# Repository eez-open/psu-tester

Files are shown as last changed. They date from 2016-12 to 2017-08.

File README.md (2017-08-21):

PCB tester for H24005 power supply's Power board r5B12 (or later) and AUX power module that can be used during PCBA and final quality assurance process. Require [Arduino Leonardo](https://www.arduino.cc/en/Main/ArduinoBoardLeonardo) board (attached on the opposite side of the PCB) and sketch with various test cases.

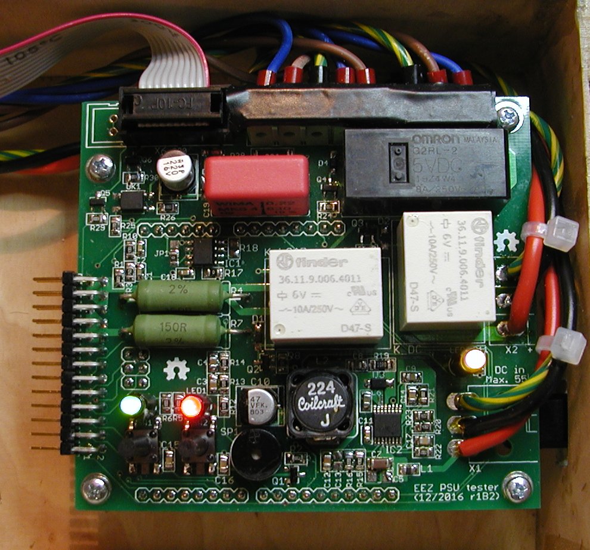
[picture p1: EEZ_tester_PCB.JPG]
EEZ tester


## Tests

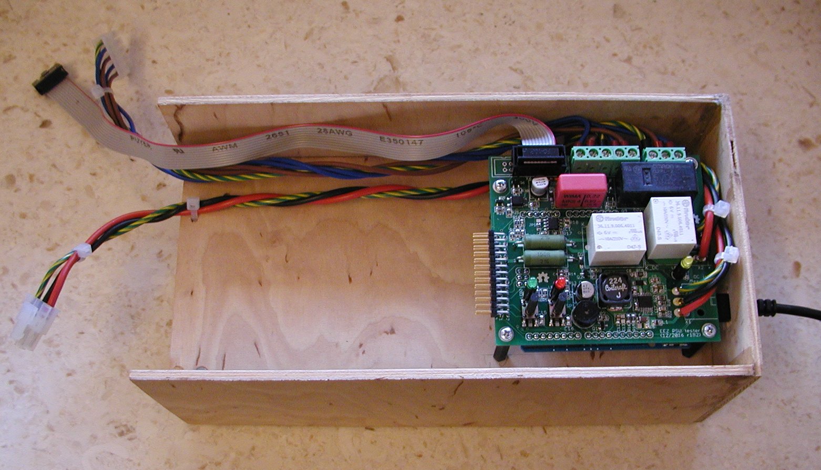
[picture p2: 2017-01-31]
EEZ tester (top view).JPG

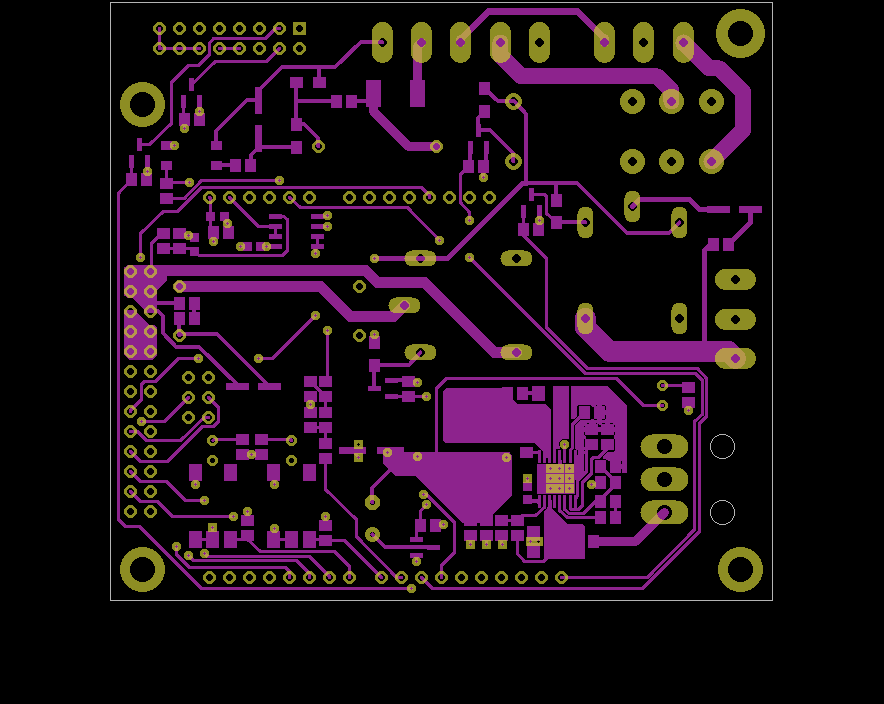
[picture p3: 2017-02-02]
EEZ tester r1B3 (top).png

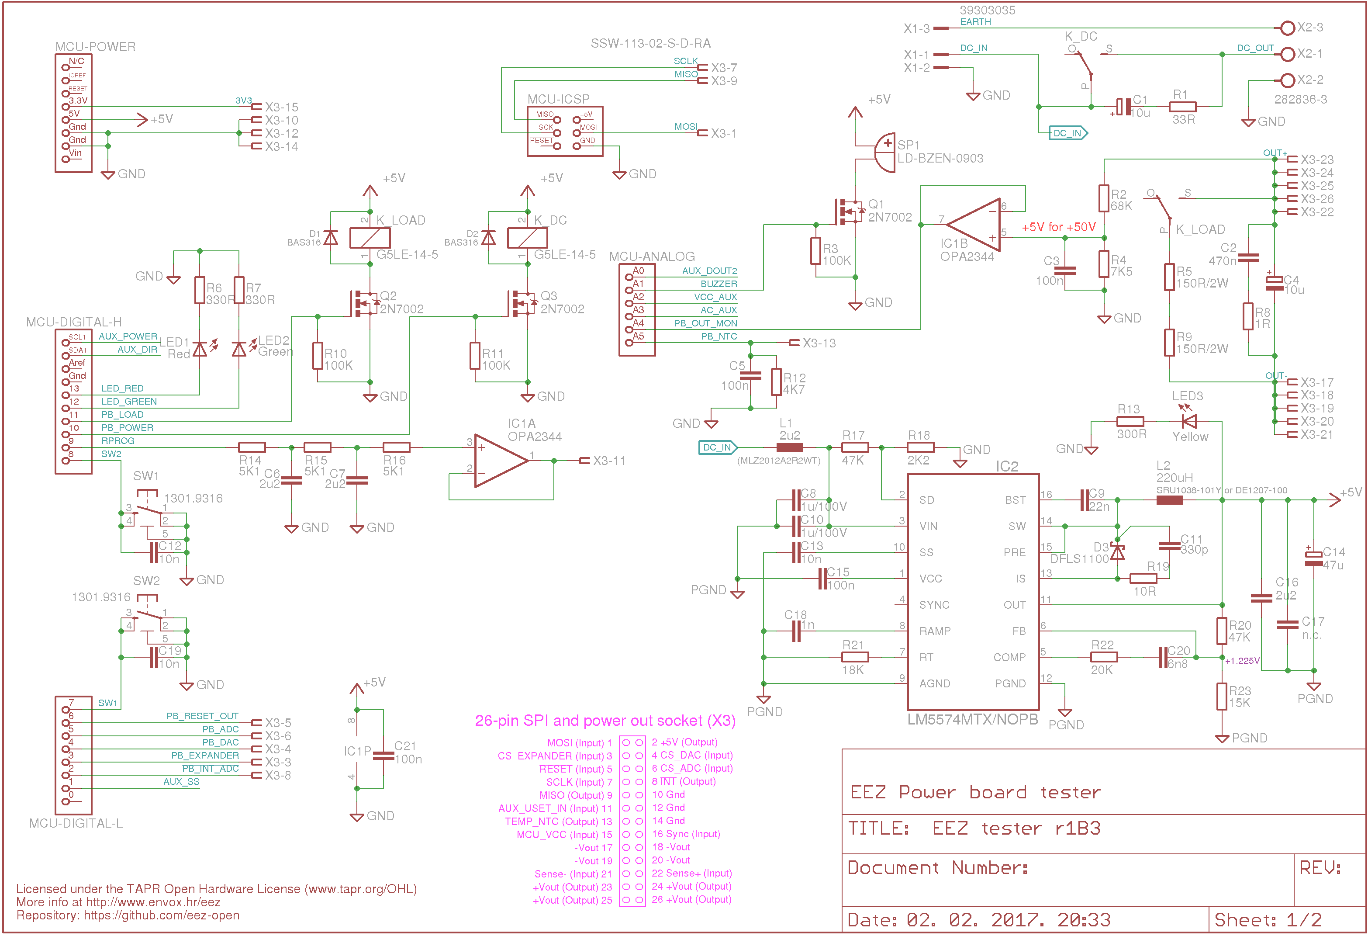
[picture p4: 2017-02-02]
EEZ tester r1B3 Sheet1of2.png

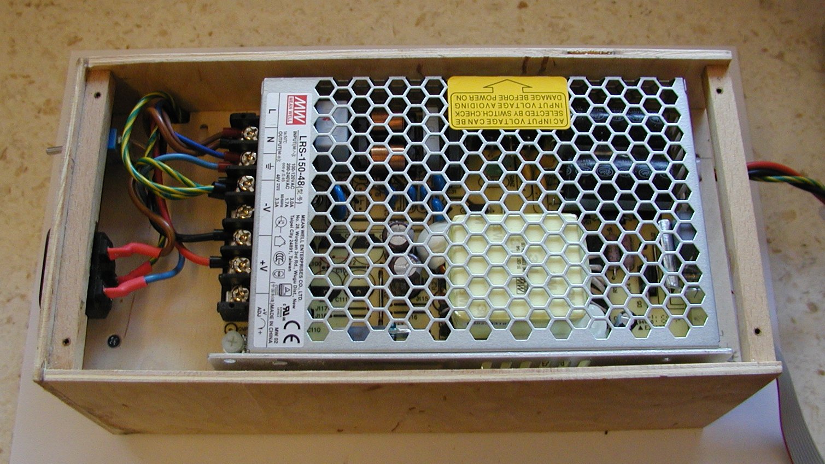
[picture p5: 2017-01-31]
EEZ tester (bottom view).JPG

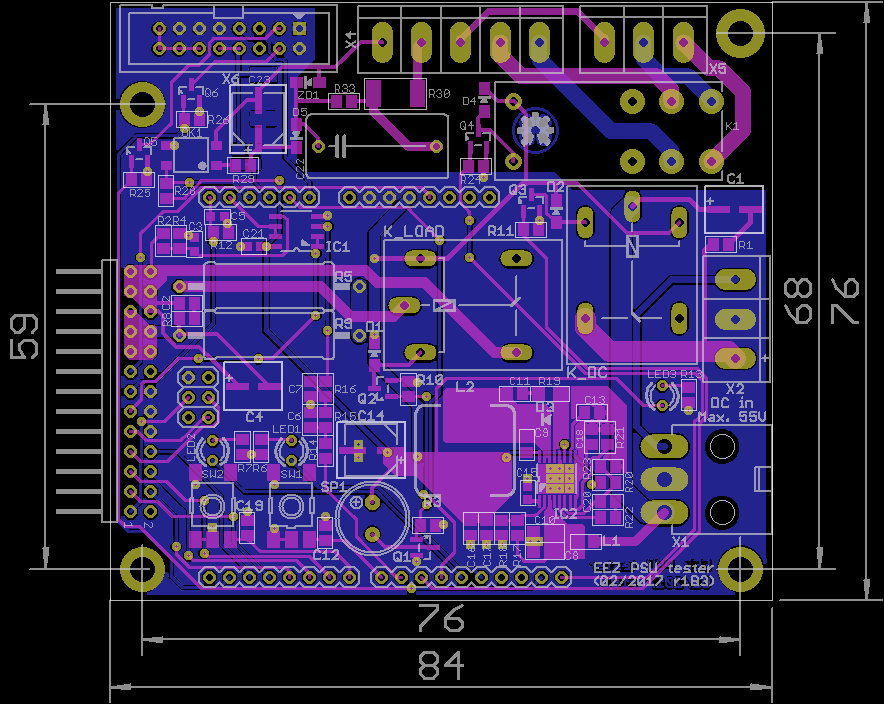
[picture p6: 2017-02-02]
EEZ tester r1B3 (all).png

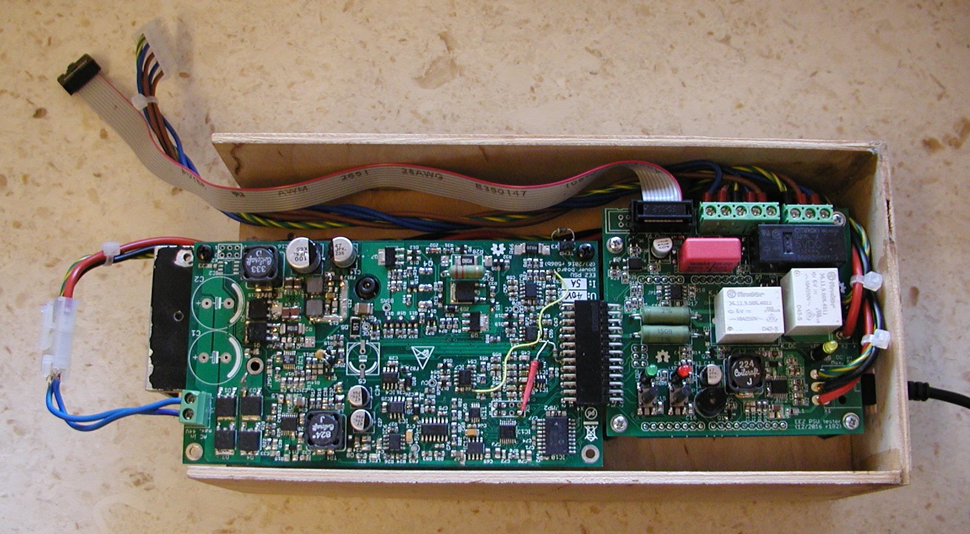
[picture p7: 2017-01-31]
EEZ tester with Power board.JPG

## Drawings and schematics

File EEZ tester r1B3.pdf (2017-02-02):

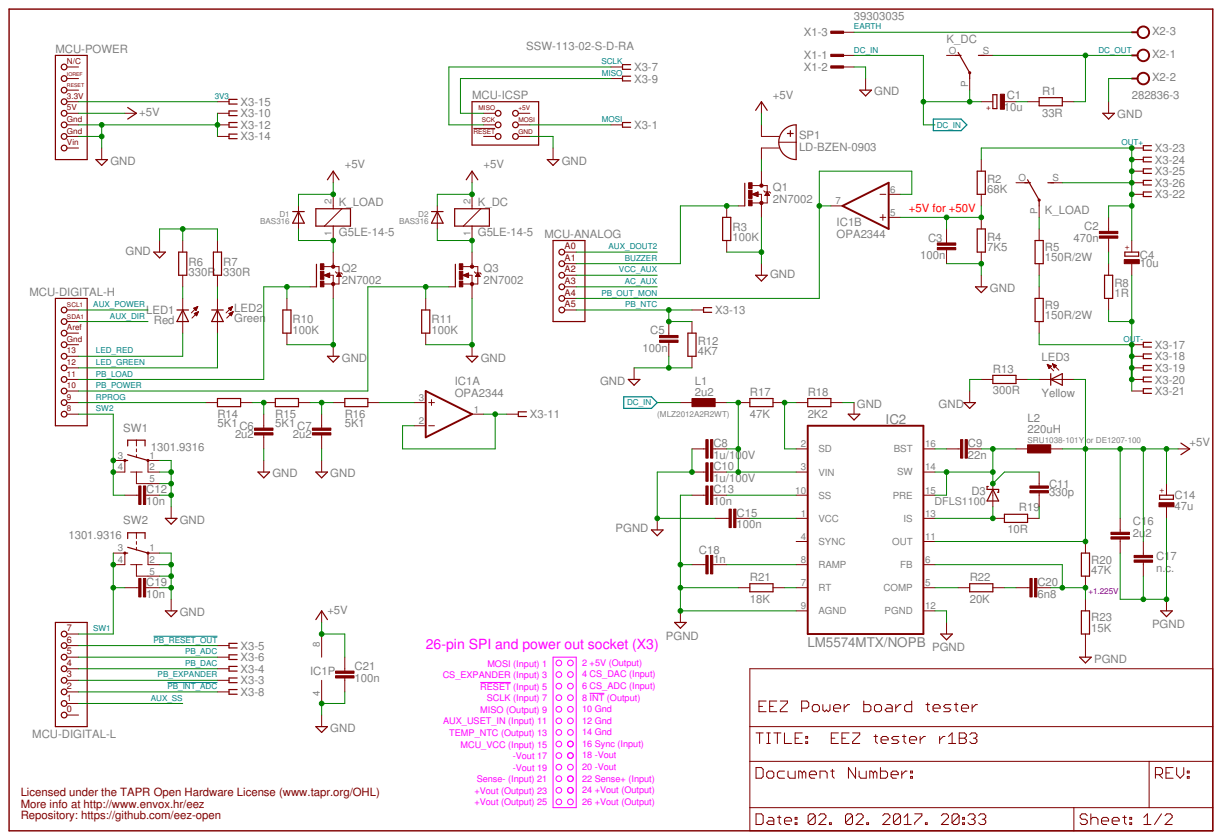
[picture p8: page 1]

18 -Vout 16 Sync (Input) 14 Gnd Sense- (Input) 21 +Vout (Output) 23 +Vout (Output) 25
-Vout 19 TEMP_NTC (Output) 13

24 +Vout (Output) 26 +Vout (Output) 22 Sense+ (Input) 20 -Vout

Licensed under the TAPR Open Hardware License (www.tapr.org/OHL)
Repository: https://github.com/eez-open More info at http://www.envox.hr/eez

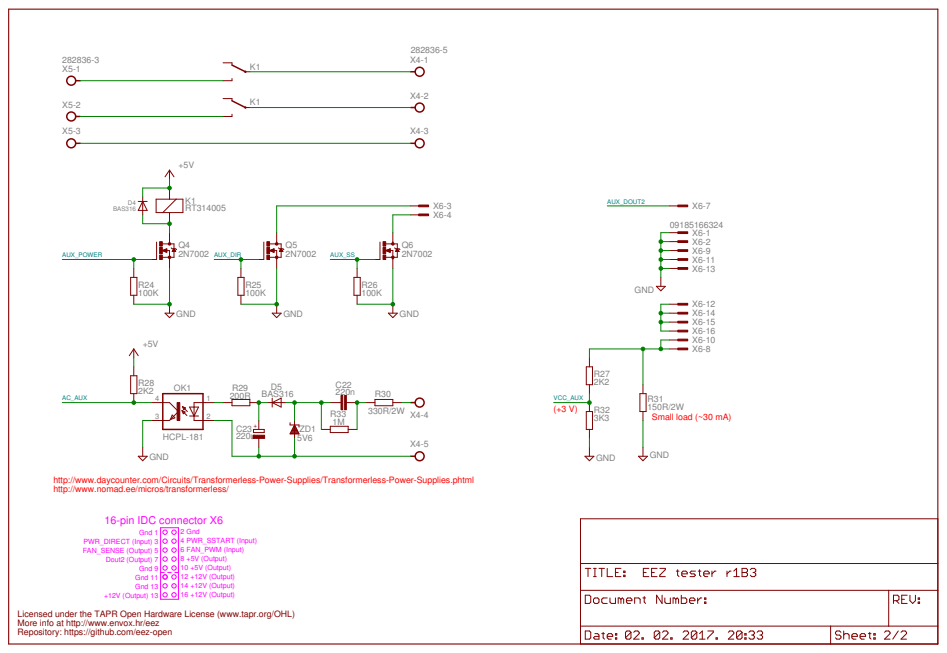
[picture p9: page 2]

http://www.daycounter.com/Circuits/Transformerless-Power-Supplies/Transformerless-Power-Supplies.phtml
http://www.nomad.ee/micros/transformerless/

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

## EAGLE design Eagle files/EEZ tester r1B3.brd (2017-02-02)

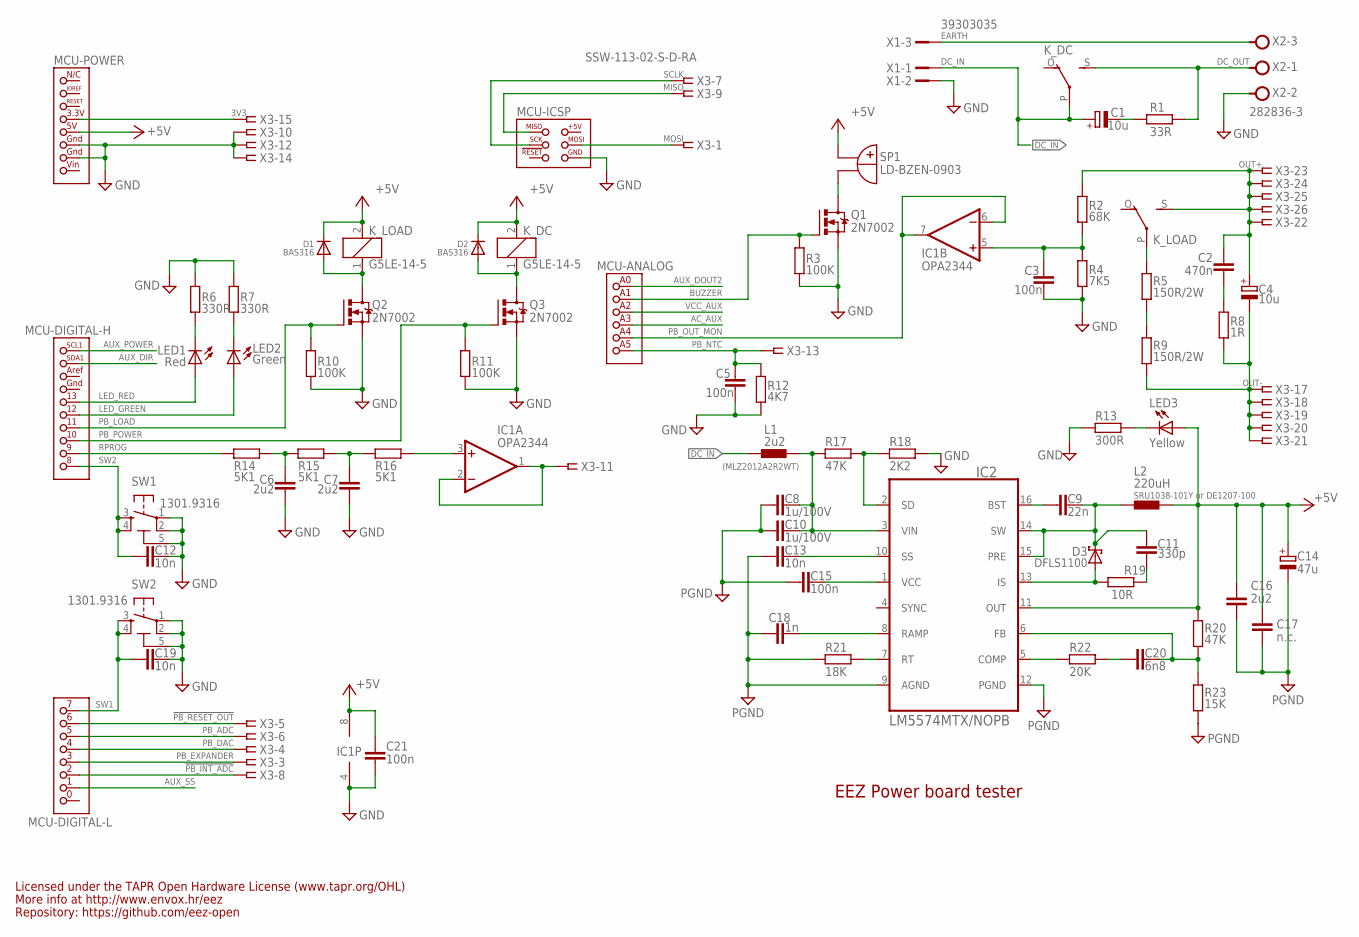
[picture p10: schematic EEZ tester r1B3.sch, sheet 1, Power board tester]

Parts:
C1, C4: 10u; PANASONIC_C
C2: 470n; C0805
C3, C5, C15, C21: 100n; C0603
C6, C7, C16: 2u2; C0805
C8, C10: 1u/100V; C1206
C9: 22n; C0805
C11: 330p; C0805
C12, C13, C19: 10n; C0805
C14: 47u; CAPAE660X610N
C17: n.c.; C0805
C18: 1n; C0805
C20: 6n8; C0805
D1, D2: BAS316; SOD323-W
D3: DFLS1100; SOD123
IC1: OPA2344; SOIC127P600X173-8N
IC2: LM5574MTX/NOPB; SOP65P640X110-16N
K_DC: G5LE-14-5; G5LE
K_LOAD: G5LE-14-5; G5LE
L1: 2u2; 0805
L2: 220uH; MSS1278
LED1: Red; LED3MM
LED2: Green; LED3MM
LED3: Yellow; LED3MM
MCU: ARDUINO_LEONARDO
Q1: 2N7002; SOT103P240X110-3N
Q2, Q3: 2N7002; SOT103P240X110-3N; MPN 2N7002-7-F
R1: 33R; R0805
R2: 68K; R0805
R3, R10, R11: 100K; R0805
R4: 7K5; R0805
R5, R9: 150R/2W; 0617/22
R6, R7: 330R; R0805
R8: 1R; R0805
R12: 4K7; R0805
R13: 300R; R0805
R14, R15, R16: 5K1; R0805
R17, R20: 47K; R0805
R18: 2K2; R0805
R19: 10R; R1206
R21: 18K; R0805
R22: 20K; R0805
R23: 15K; R0805
SP1: LD-BZEN-0903
SW1, SW2: 1301.9316; TACTM-6XN
X1: 39303035; MINIFIT_6659-3
X2: 282836-3; TBLOCK5.0_3
X3: SSW-113-02-S-D-RA; TSW-113-02-S-D-RA

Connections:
3V3: MCU.3.3V (3V3), X3.15
!PB_INT_ADC: MCU.2 (2(PE4)), X3.8
!PB_RESET_OUT: MCU.6 (6(PH3)), X3.5
+5V: C14.1 (+), C16.1, C17.1, C21.1, D1.C, D2.C, IC1.8 (V+), IC2.11 (OUT), K_DC.2, K_LOAD.2, L2.2, LED3.A, MCU.5V, R20.1, SP1.+B (+); also elsewhere on the board
AC_AUX: MCU.A3 (ADC3); also elsewhere on the board
AUX_DIR: MCU.SDA1; also elsewhere on the board
AUX_DOUT2: MCU.A0 (ADC0); also elsewhere on the board
AUX_POWER: MCU.SCL1; also elsewhere on the board
AUX_SS: MCU.1 (1(PE1)); also elsewhere on the board
AUX_USET: IC1.1 (OUT), IC1.2 (-IN), X3.11
BUZZER: MCU.A1 (ADC1), Q1.1 (G), R3.2
DC_IN: C1.1 (+), K_DC.P, L1.1, X1.1
DC_OUT: K_DC.S, R1.2, X2.1
DC_PREG1: C8.1, C10.1, IC2.3 (VIN), L1.2, R17.2
EARTH: X1.3, X2.3
GND: C3.1, C5.1, C6.2, C7.2, C8.2, C10.2, C12.2, C13.2, C14.2 (-), C15.1, C16.2, C17.2, C18.1, C19.2, C21.2, IC1.4 (V-), IC2.9 (AGND), IC2.12 (PGND), MCU.GND1, MCU.GND2, MCU.ICSP_GND (GND), Q1.2 (S), Q2.2 (S), Q3.2 (S), R3.1, R4.2, R6.2, R7.2, R10.1, R11.1, R12.2, R13.1, R18.1, R21.2, R23.2, SW1.1, SW1.2, SW1.5 (5-GND), SW2.1, SW2.2, SW2.5 (5-GND), X1.2, X2.2, X3.10, X3.12, X3.14; also elsewhere on the board
IS: D3.A, IC2.13 (IS), R19.1
LED_GREEN: LED2.A, MCU.12
LED_RED: LED1.A, MCU.13
MISO: MCU.ICSP_MISO (MISO), X3.9
MOSI: MCU.ICSP_MOSI (MOSI), X3.1
unnamed: R5.1, R9.2
unnamed: K_LOAD.P, R5.2
unnamed: LED3.K (C), R13.2
unnamed: C1.2 (-), R1.1
unnamed: C3.2, IC1.5 (+IN), R2.2, R4.1
unnamed: C7.1, R15.1, R16.2
unnamed: Q1.3 (D), SP1.-B (-)
unnamed: C6.1, R14.1, R15.2
unnamed: LED1.K (C), R6.1
unnamed: LED2.K (C), R7.1
unnamed: D2.A, K_DC.1, Q3.3 (D)
unnamed: D1.A, K_LOAD.1, Q2.3 (D)
unnamed: C11.2, R19.2
unnamed: C20.2, R22.2
unnamed: C2.2, R8.2
unnamed: C20.1, IC2.6 (FB), R20.2, R23.1
unnamed: C9.2, IC2.16 (BST)
unnamed: IC2.5 (COMP), R22.1
unnamed: IC2.7 (RT), R21.1
unnamed: C15.2, IC2.1 (VCC)
unnamed: C18.2, IC2.8 (RAMP)
unnamed: C13.1, IC2.10 (SS)
unnamed: IC2.2 (SD), R17.1, R18.2
unnamed: IC1.3 (+IN), R16.1
OUT+: C2.1, C4.1 (+), K_LOAD.S, R2.1, X3.22, X3.23, X3.24, X3.25, X3.26
OUT-: C4.2 (-), R8.1, R9.1, X3.17, X3.18, X3.19, X3.20, X3.21
PB_ADC: MCU.5 (5(PE3)), X3.6
PB_DAC: MCU.4 (4(PG5)), X3.4
PB_EXPANDER: MCU.3 (3(PE5)), X3.3
PB_LOAD: MCU.11, Q2.1 (G), R10.2
PB_NTC: C5.2, MCU.A5 (ADC5), R12.1, X3.13
PB_OUT_MON: IC1.6 (-IN), IC1.7 (OUT), MCU.A4 (ADC4)
PB_POWER: MCU.10, Q3.1 (G), R11.2
RPROG: MCU.9 (9(PH6)), R14.2
SCLK: MCU.ICSP_SCK (SCK), X3.7
SW: C9.1, C11.1, D3.C, IC2.14 (SW), IC2.15 (PRE), L2.1
SW1: C19.1, MCU.7 (7(PH4)), SW2.3, SW2.4
SW2: C12.1, MCU.8 (8(PH5)), SW1.3, SW1.4
VCC_AUX: MCU.A2 (ADC2); also elsewhere on the board

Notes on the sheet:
EEZ Power board tester
Licensed under the TAPR Open Hardware License (www.tapr.org/OHL)
Repository: https://github.com/eez-open
More info at http://www.envox.hr/eez
(MLZ2012A2R2WT)
SRU1038-101Y or DE1207-100

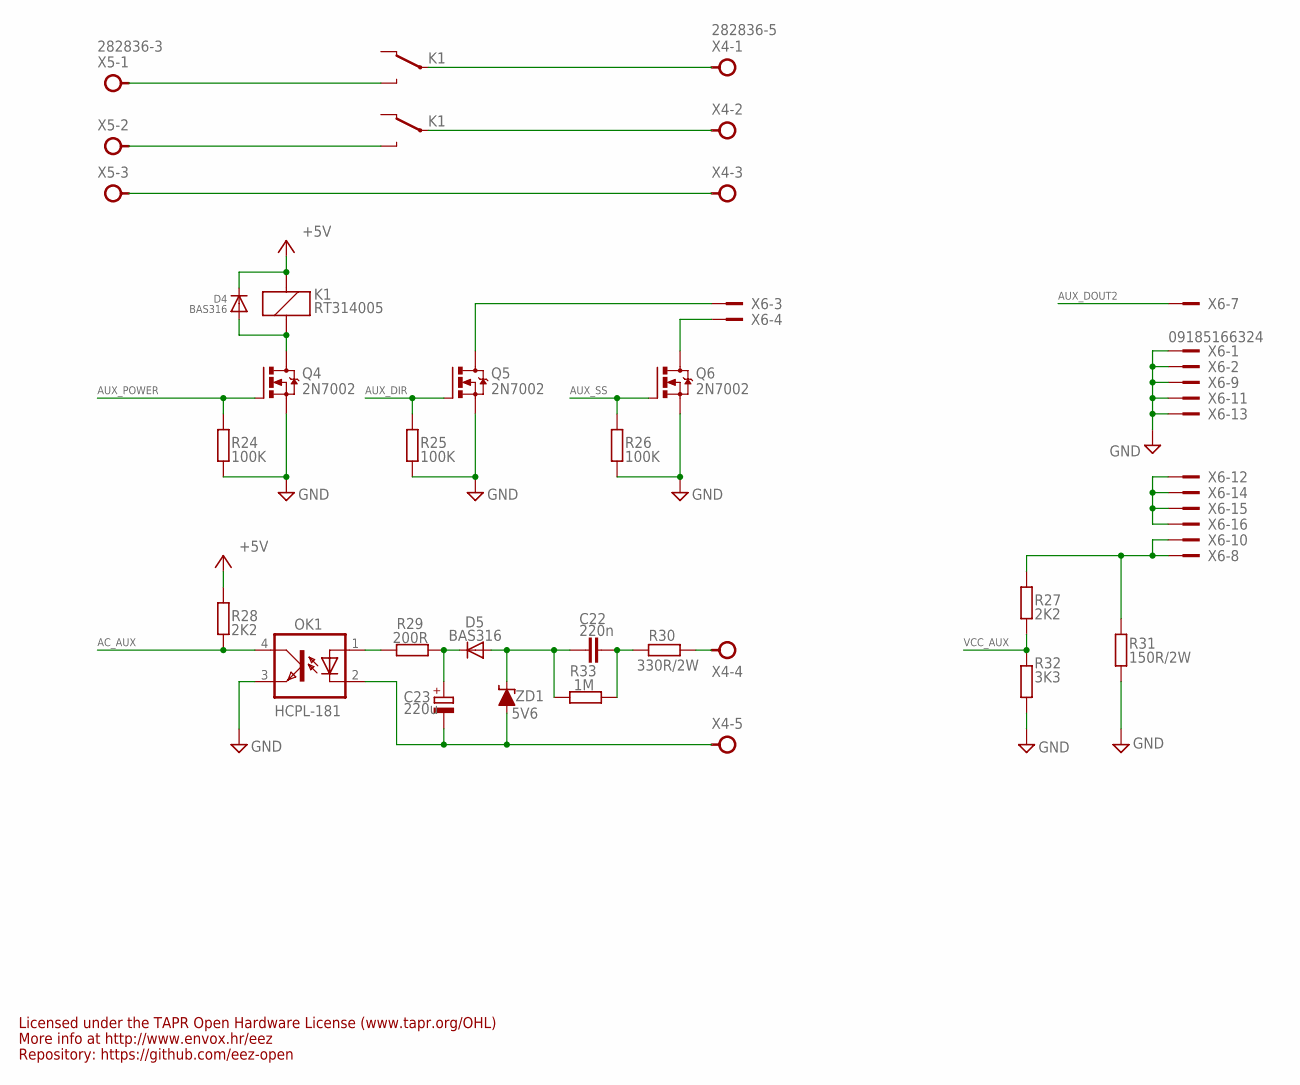
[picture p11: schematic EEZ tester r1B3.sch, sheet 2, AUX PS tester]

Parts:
C22: 220n; C150-084X183
C23: 220u; CAPAE660X610N
D4, D5: BAS316; SOD323-W
K1: RT314005; RT-C/016A5_ROUND
OK1: HCPL-181
Q4, Q5, Q6: 2N7002; SOT103P240X110-3N; MPN 2N7002-7-F
R24, R25, R26: 100K; R0805
R27, R28: 2K2; R0805
R29: 200R; R0805
R30: 330R/2W; R2512
R31: 150R/2W; R2512
R32: 3K3; R0805
R33: 1M; R0805
X4: 282836-5; TBLOCK5.0_5
X5: 282836-3; TBLOCK5.0_3
X6: 09185166324; IDC-16PIN
ZD1: 5V6; SOD323-W

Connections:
+5V: D4.C, K1.A2 (C1), R28.2; also elsewhere on the board
AC_AUX: OK1.4 (COL), R28.1; also elsewhere on the board
AUX_DIR: Q5.1 (G), R25.2; also elsewhere on the board
AUX_DOUT2: X6.7; also elsewhere on the board
AUX_POWER: Q4.1 (G), R24.2; also elsewhere on the board
AUX_SS: Q6.1 (G), R26.2; also elsewhere on the board
GND: OK1.3 (EMIT), Q4.2 (S), Q5.2 (S), Q6.2 (S), R24.1, R25.1, R26.1, R31.2, R32.1, X6.1, X6.2, X6.9, X6.11, X6.13; also elsewhere on the board
unnamed: Q5.3 (D), X6.3
unnamed: K1.11A, X4.2
unnamed: D4.A, K1.A1 (C2), Q4.3 (D)
unnamed: K1.11B, X4.1
unnamed: K1.14B (O), X5.1
unnamed: K1.14A (O), X5.2
unnamed: X4.3, X5.3
unnamed: R30.1, X4.4
unnamed: C22.2, R30.2, R33.1
unnamed: C22.1, D5.A, R33.2, ZD1.C
unnamed: C23.2 (-), OK1.2 (C), X4.5, ZD1.A
unnamed: Q6.3 (D), X6.4
unnamed: OK1.1 (A), R29.2
unnamed: C23.1 (+), D5.C, R29.1
unnamed: R27.2, R31.1, X6.8, X6.10
unnamed: X6.12, X6.14, X6.15, X6.16
VCC_AUX: R27.1, R32.2; also elsewhere on the board

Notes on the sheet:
Licensed under the TAPR Open Hardware License (www.tapr.org/OHL)
Repository: https://github.com/eez-open
More info at http://www.envox.hr/eez

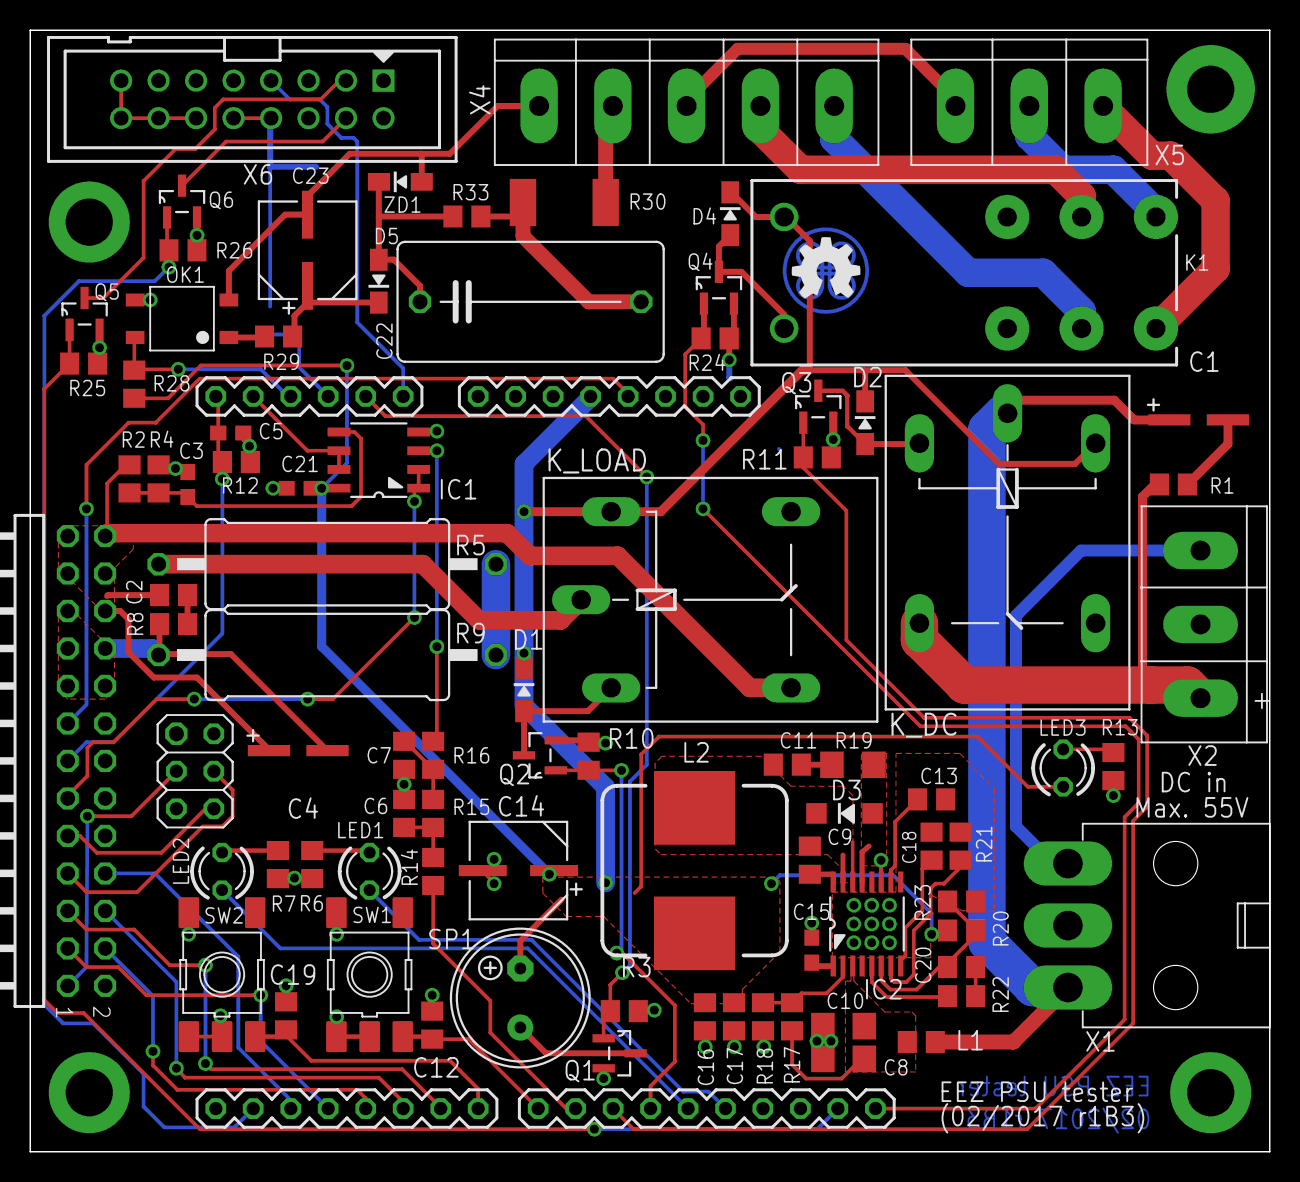
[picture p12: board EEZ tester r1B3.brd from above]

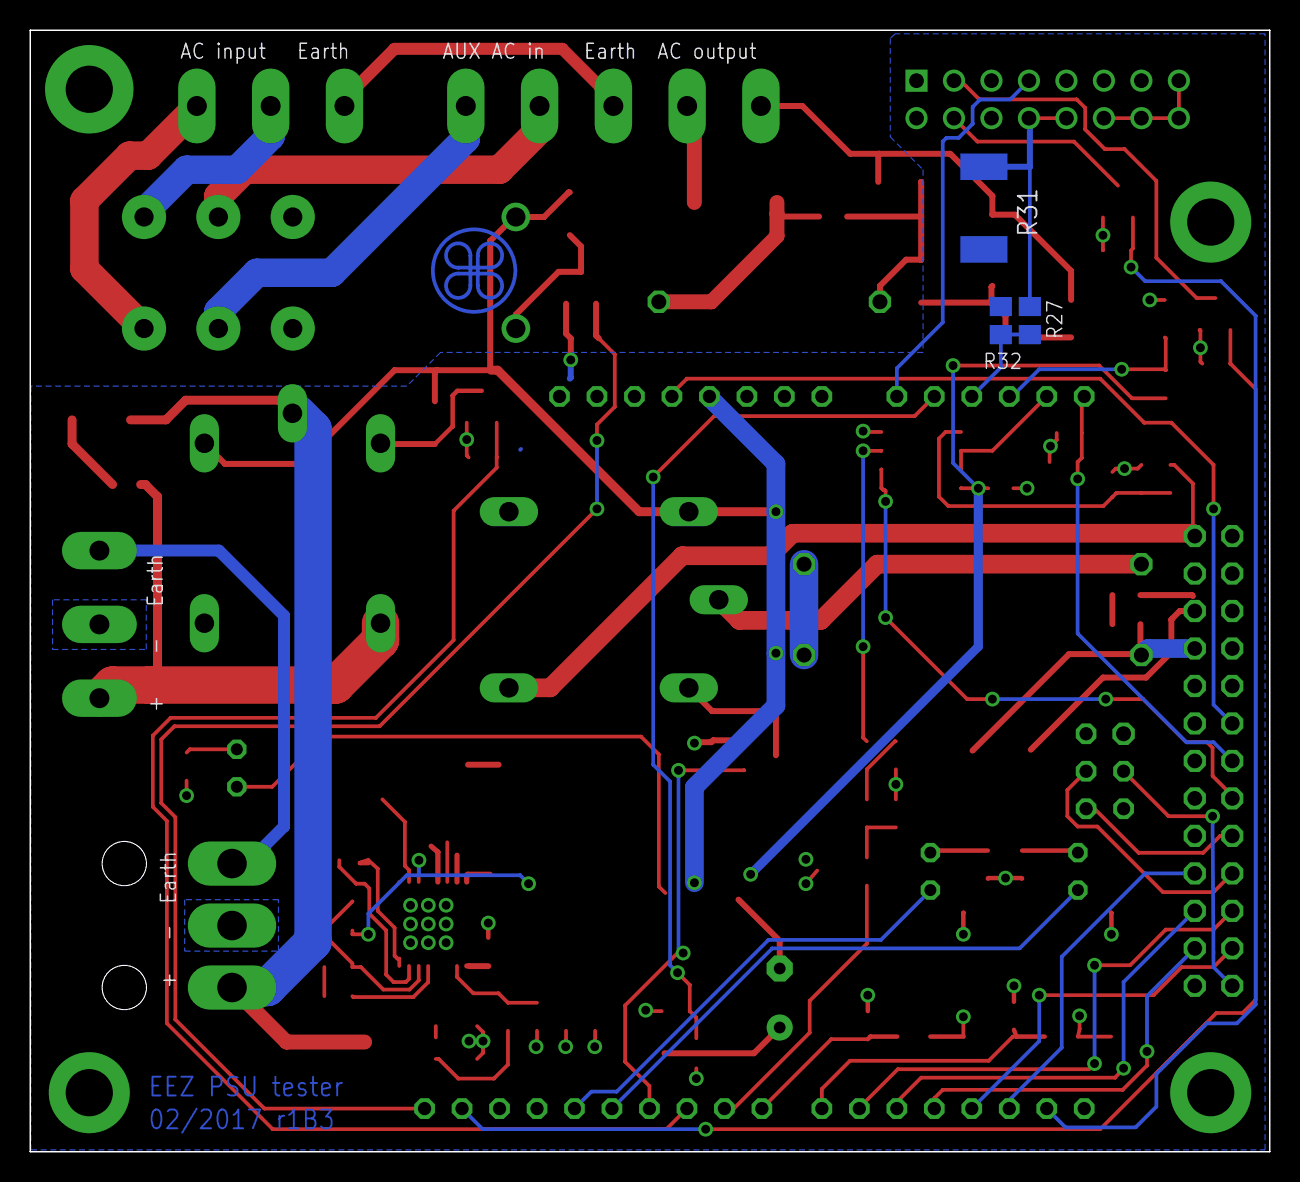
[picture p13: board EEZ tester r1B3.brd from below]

Board: 2 copper layers, 84.0 x 76.0 mm, 90 parts (3 on the bottom side), 76 nets.

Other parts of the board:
EEZ_SIGNATURE2: SIGNATURESMALL; SIGNATURE_5MM

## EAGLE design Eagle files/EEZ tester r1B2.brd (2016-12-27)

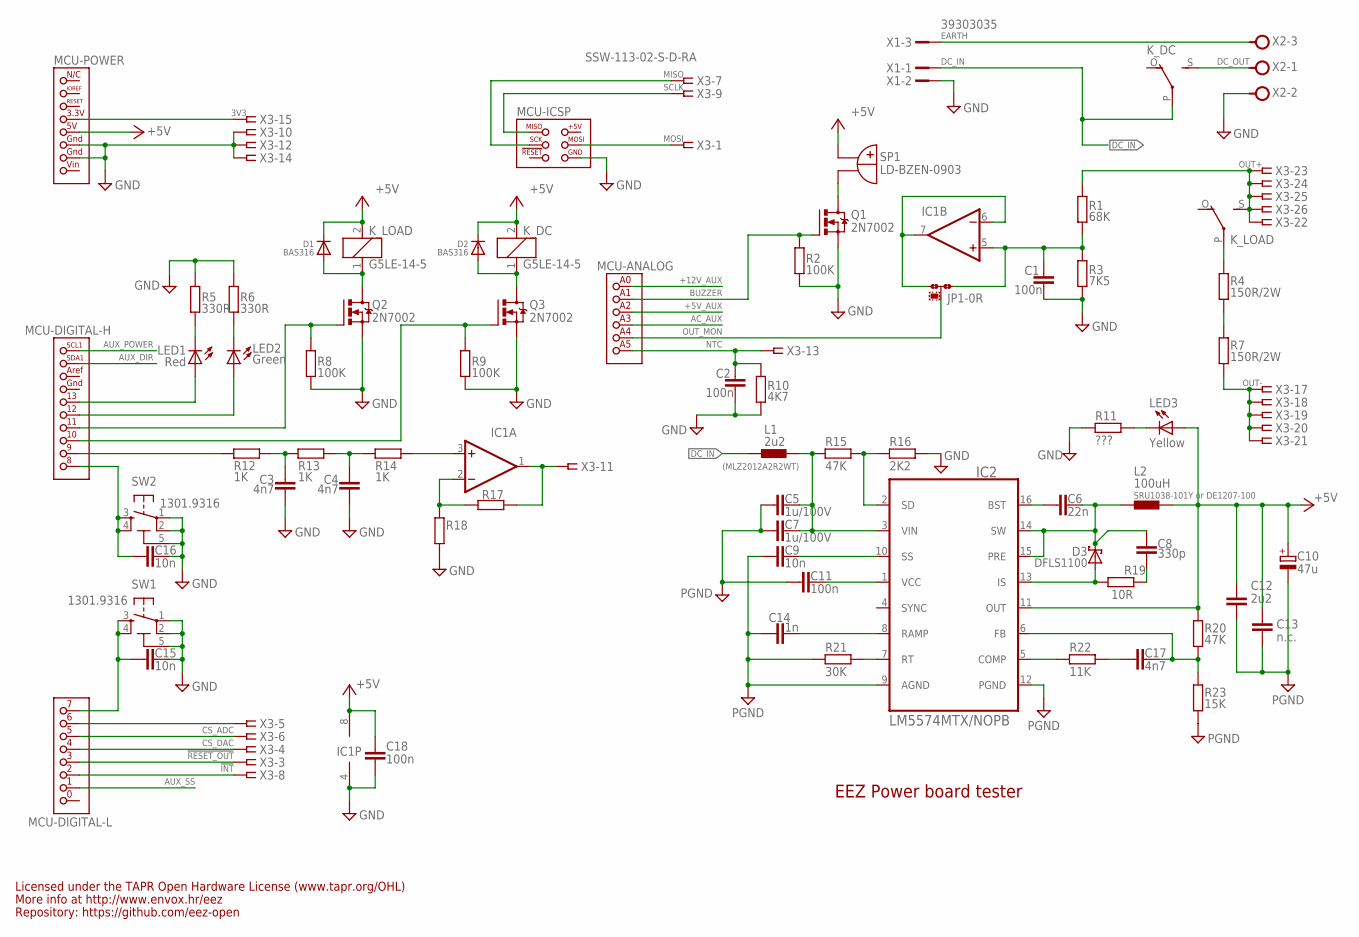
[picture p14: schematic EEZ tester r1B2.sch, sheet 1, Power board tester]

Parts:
C1, C2, C11, C18: 100n; C0603
C3, C4, C17: 4n7; C0805
C5, C7: 1u/100V; C1206
C6: 22n; C0805
C8: 330p; C0805
C9, C15, C16: 10n; C0805
C10: 47u; CAPAE660X610N
C12: 2u2; C0805
C13: n.c.; C0805
C14: 1n; C0805
D1, D2: BAS316; SOD323-W
D3: DFLS1100; SOD123
IC1: TL072SOIC8; SOIC127P600X173-8N
IC2: LM5574MTX/NOPB; SOP65P640X110-16N
JP1: 0R-JUMPA; A0R-JMP
K_DC: G5LE-14-5; G5LE
K_LOAD: G5LE-14-5; G5LE
L1: 2u2; 0805
L2: 100uH; MSS1278
LED1: Red; LED3MM
LED2: Green; LED3MM
LED3: Yellow; LED3MM
MCU: ARDUINO_LEONARDO
Q1: 2N7002; SOT103P240X110-3N
Q2, Q3: 2N7002; SOT103P240X110-3N; MPN 2N7002-7-F
R1: 68K; R0805
R2, R8, R9: 100K; R0805
R3: 7K5; R0805
R4, R7: 150R/2W; 0617/22
R5, R6: 330R; R0805
R10: 4K7; R0805
R11: ???; R0805
R12, R13, R14: 1K; R0805
R15, R20: 47K; R0805
R16: 2K2; R0805
R17, R18: R-EU_R0805; R0805
R19: 10R; R1206
R21: 30K; R0805
R22: 11K; R0805
R23: 15K; R0805
SP1: LD-BZEN-0903
SW1, SW2: 1301.9316; TACTM-6XN
X1: 39303035; MINIFIT_6659-3
X2: TBLOCK5.0_3A; TBLOCK5.0_3
X3: SSW-113-02-S-D-RA; TSW-113-02-S-D-RA

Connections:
3V3: MCU.3.3V (3V3), X3.15
!INT: MCU.2 (2(PE4)), X3.8
!RESET_OUT: MCU.3 (3(PE5)), X3.3
+5V: C10.1 (+), C12.1, C13.1, C18.1, D1.C, D2.C, IC1.8 (V+), IC2.11 (OUT), K_DC.2, K_LOAD.2, L2.2, LED3.A, MCU.5V, R20.1, SP1.+B (+); also elsewhere on the board
+5V_AUX: MCU.A2 (ADC2); also elsewhere on the board
+12V_AUX: MCU.A0 (ADC0); also elsewhere on the board
AC_AUX: MCU.A3 (ADC3); also elsewhere on the board
AUX_DIR: MCU.SDA1; also elsewhere on the board
AUX_POWER: MCU.SCL1; also elsewhere on the board
AUX_SS: MCU.1 (1(PE1)); also elsewhere on the board
AUX_USET: IC1.1 (OUT), R17.2, X3.11
BUZZER: MCU.A1 (ADC1), Q1.1 (G), R2.2
CS_ADC: MCU.5 (5(PE3)), X3.6
CS_DAC: MCU.4 (4(PG5)), X3.4
CS_EXPANDER: MCU.6 (6(PH3)), X3.5
DC_IN: K_DC.P, L1.1, X1.1
DC_OUT: K_DC.S, X2.1
DC_PREG1: C5.1, C7.1, IC2.3 (VIN), L1.2, R15.2
EARTH: X1.3, X2.3
GND: C1.1, C2.1, C3.2, C4.2, C5.2, C7.2, C9.2, C10.2 (-), C11.1, C12.2, C13.2, C14.1, C15.2, C16.2, C18.2, IC1.4 (V-), IC2.9 (AGND), IC2.12 (PGND), MCU.GND1, MCU.GND2, MCU.ICSP_GND (GND), Q1.2 (S), Q2.2 (S), Q3.2 (S), R2.1, R3.2, R5.2, R6.2, R8.1, R9.1, R10.2, R11.1, R16.1, R18.2, R21.2, R23.2, SW1.1, SW1.2, SW1.5 (5-GND), SW2.1, SW2.2, SW2.5 (5-GND), X1.2, X2.2, X3.10, X3.12, X3.14; also elsewhere on the board
IS: D3.A, IC2.13 (IS), R19.1
MISO: MCU.ICSP_SCK (SCK), X3.7
MOSI: MCU.ICSP_MOSI (MOSI), X3.1
unnamed: R4.1, R7.2
unnamed: K_LOAD.P, R4.2
unnamed: LED3.K (C), R11.2
unnamed: IC1.6 (-IN), IC1.7 (OUT), JP1.3
unnamed: MCU.9 (9(PH6)), R12.2
unnamed: C1.2, IC1.5 (+IN), JP1.1, R1.2, R3.1
unnamed: MCU.11, Q2.1 (G), R8.2
unnamed: C4.1, R13.1, R14.2
unnamed: Q1.3 (D), SP1.-B (-)
unnamed: C15.1, MCU.7 (7(PH4)), SW1.3, SW1.4
unnamed: LED2.A, MCU.12
unnamed: C3.1, R12.1, R13.2
unnamed: LED1.A, MCU.13
unnamed: LED1.K (C), R5.1
unnamed: LED2.K (C), R6.1
unnamed: C16.1, MCU.8 (8(PH5)), SW2.3, SW2.4
unnamed: MCU.10, Q3.1 (G), R9.2
unnamed: D2.A, K_DC.1, Q3.3 (D)
unnamed: D1.A, K_LOAD.1, Q2.3 (D)
unnamed: C8.2, R19.2
unnamed: C17.2, R22.2
unnamed: C17.1, IC2.6 (FB), R20.2, R23.1
unnamed: C6.2, IC2.16 (BST)
unnamed: IC2.5 (COMP), R22.1
unnamed: IC2.7 (RT), R21.1
unnamed: C11.2, IC2.1 (VCC)
unnamed: C14.2, IC2.8 (RAMP)
unnamed: C9.1, IC2.10 (SS)
unnamed: IC2.2 (SD), R15.1, R16.2
unnamed: IC1.2 (-IN), R17.1, R18.1
unnamed: IC1.3 (+IN), R14.1
NTC: C2.2, MCU.A5 (ADC5), R10.1, X3.13
OUT+: K_LOAD.S, R1.1, X3.22, X3.23, X3.24, X3.25, X3.26
OUT-: R7.1, X3.17, X3.18, X3.19, X3.20, X3.21
OUT_MON: JP1.2, MCU.A4 (ADC4)
SCLK: MCU.ICSP_MISO (MISO), X3.9
SW1: C6.1, C8.1, D3.C, IC2.14 (SW), IC2.15 (PRE), L2.1

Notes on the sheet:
EEZ Power board tester
Licensed under the TAPR Open Hardware License (www.tapr.org/OHL)
Repository: https://github.com/eez-open
More info at http://www.envox.hr/eez
(MLZ2012A2R2WT)
SRU1038-101Y or DE1207-100

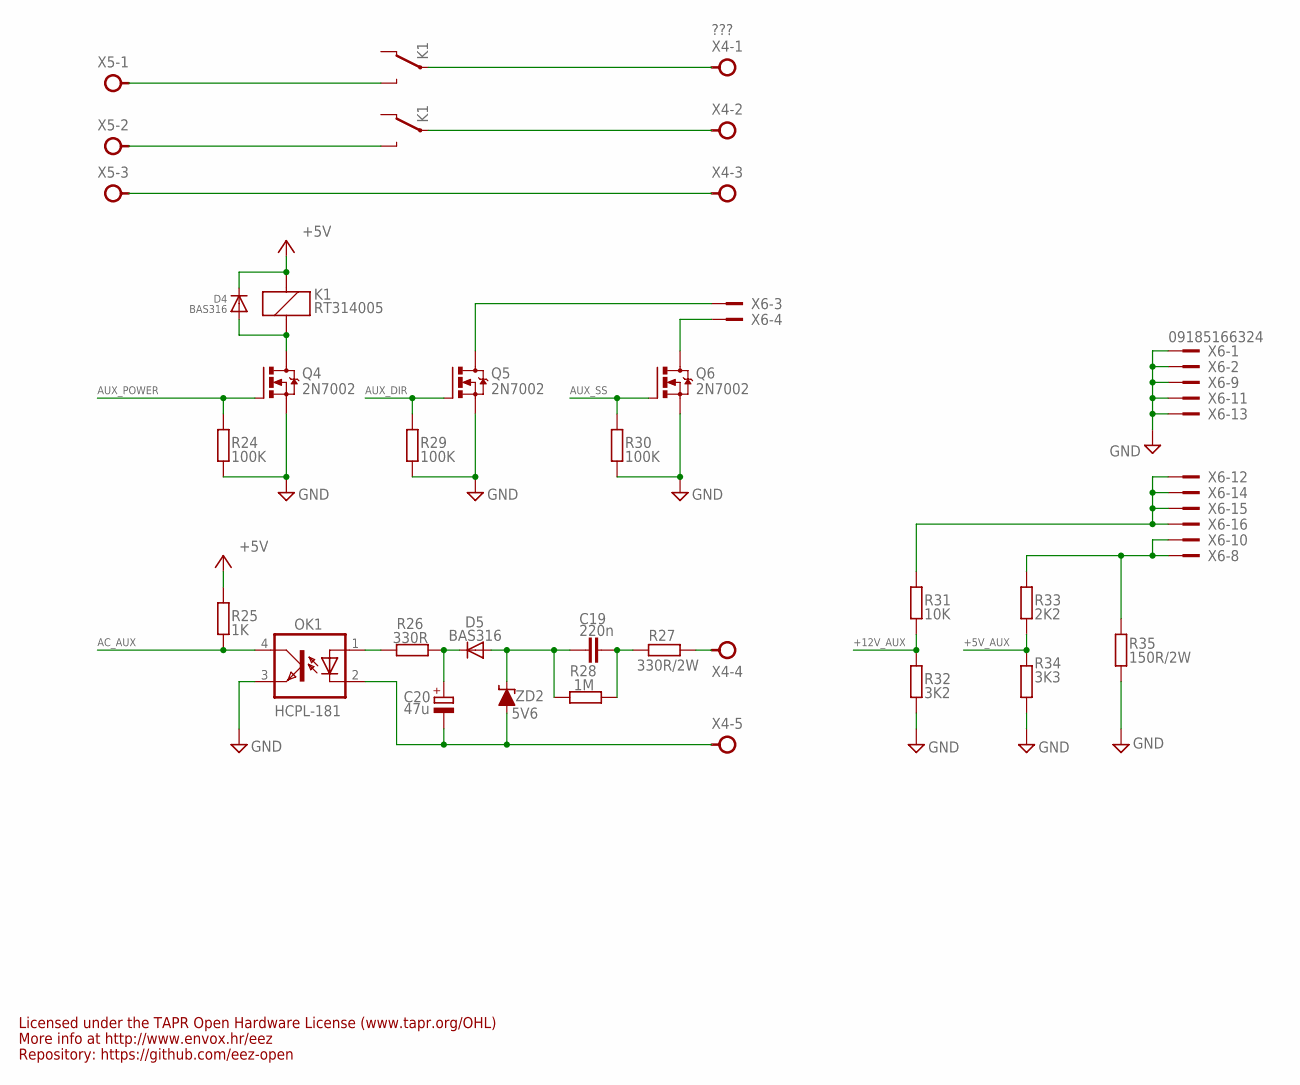
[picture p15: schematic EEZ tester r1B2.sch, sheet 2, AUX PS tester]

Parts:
C19: 220n; C150-084X183
C20: 47u; CAPAE660X610N
D4, D5: BAS316; SOD323-W
K1: RT314005; RT-C/016A5_ROUND
OK1: HCPL-181
Q4, Q5, Q6: 2N7002; SOT103P240X110-3N; MPN 2N7002-7-F
R24, R29, R30: 100K; R0805
R25: 1K; R0805
R26: 330R; R0805
R27: 330R/2W; R2512
R28: 1M; R0805
R31: 10K; R0805
R32: 3K2; R0805
R33: 2K2; R0805
R34: 3K3; R0805
R35: 150R/2W; R2512
X4: ???; TBLOCK5.0_5
X5: TBLOCK5.0_3A; TBLOCK5.0_3
X6: 09185166324; IDC-16PIN
ZD2: 5V6; SOD323-W

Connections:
+5V: D4.C, K1.A2 (C1), R25.2; also elsewhere on the board
+5V_AUX: R33.1, R34.2; also elsewhere on the board
+12V_AUX: R31.1, R32.2; also elsewhere on the board
AC_AUX: OK1.4 (COL), R25.1; also elsewhere on the board
AUX_DIR: Q5.1 (G), R29.2; also elsewhere on the board
AUX_POWER: Q4.1 (G), R24.2; also elsewhere on the board
AUX_SS: Q6.1 (G), R30.2; also elsewhere on the board
GND: OK1.3 (EMIT), Q4.2 (S), Q5.2 (S), Q6.2 (S), R24.1, R29.1, R30.1, R32.1, R34.1, R35.2, X6.1, X6.2, X6.9, X6.11, X6.13; also elsewhere on the board
unnamed: Q5.3 (D), X6.3
unnamed: D4.A, K1.A1 (C2), Q4.3 (D)
unnamed: K1.11B, X4.1
unnamed: K1.14B (O), X5.1
unnamed: K1.14A (O), X5.2
unnamed: K1.11A, X4.2
unnamed: X4.3, X5.3
unnamed: R27.1, X4.4
unnamed: C19.2, R27.2, R28.1
unnamed: C19.1, D5.A, R28.2, ZD2.C
unnamed: C20.2 (-), OK1.2 (C), X4.5, ZD2.A
unnamed: Q6.3 (D), X6.4
unnamed: OK1.1 (A), R26.2
unnamed: C20.1 (+), D5.C, R26.1
unnamed: R33.2, R35.1, X6.8, X6.10
unnamed: R31.2, X6.12, X6.14, X6.15, X6.16

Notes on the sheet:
Licensed under the TAPR Open Hardware License (www.tapr.org/OHL)
Repository: https://github.com/eez-open
More info at http://www.envox.hr/eez

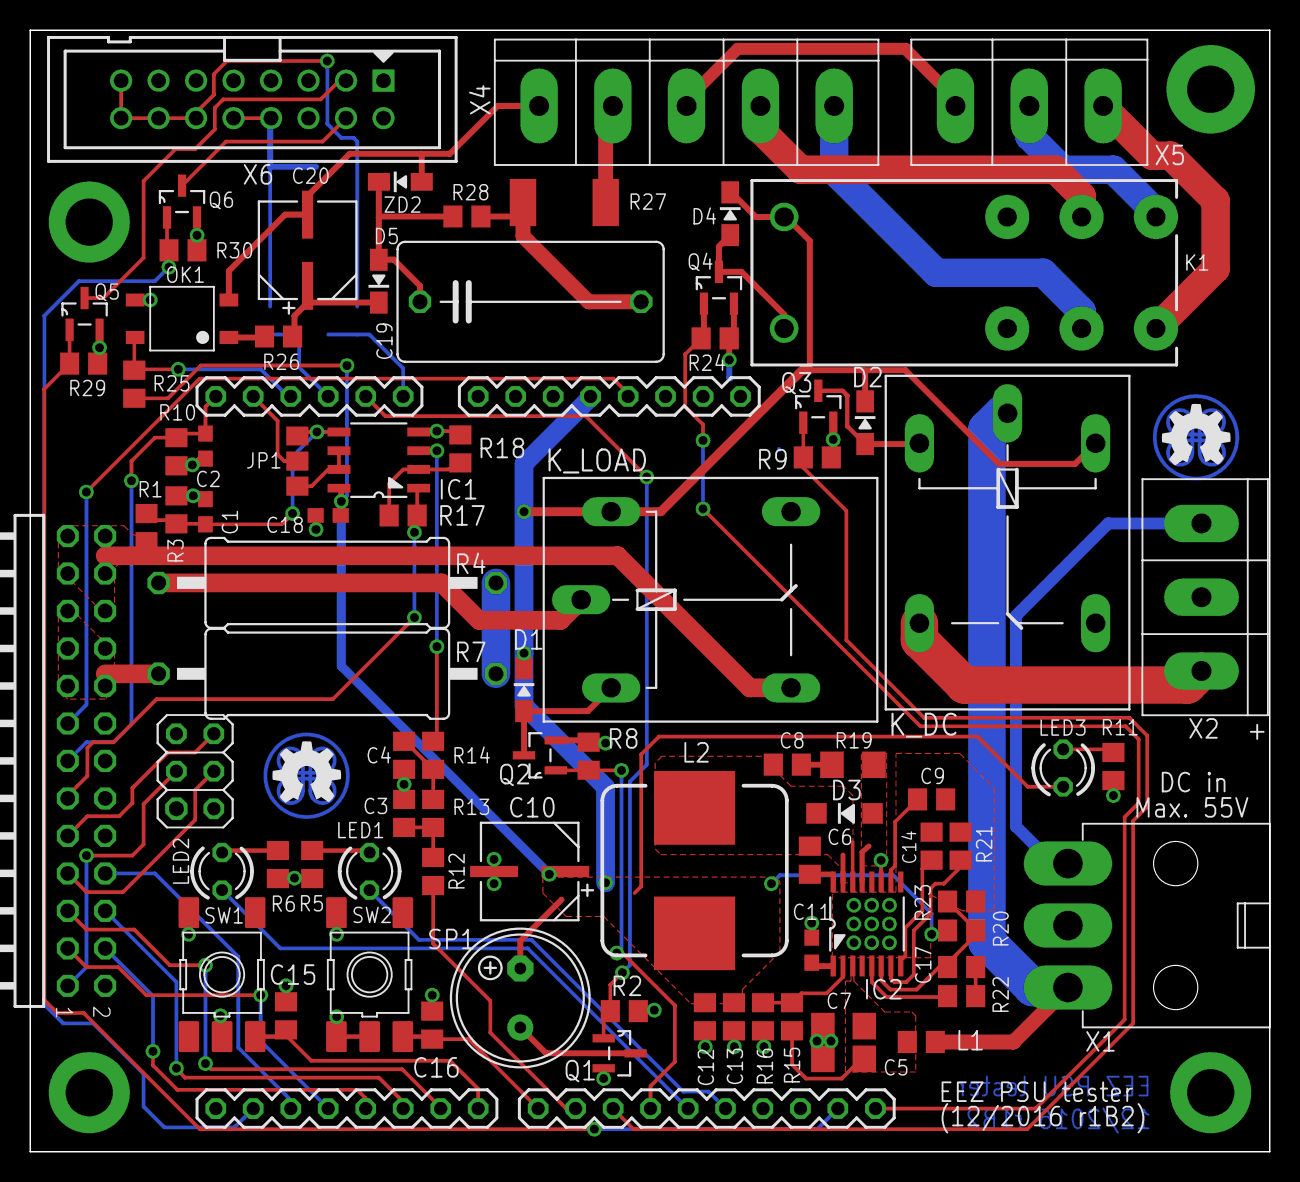
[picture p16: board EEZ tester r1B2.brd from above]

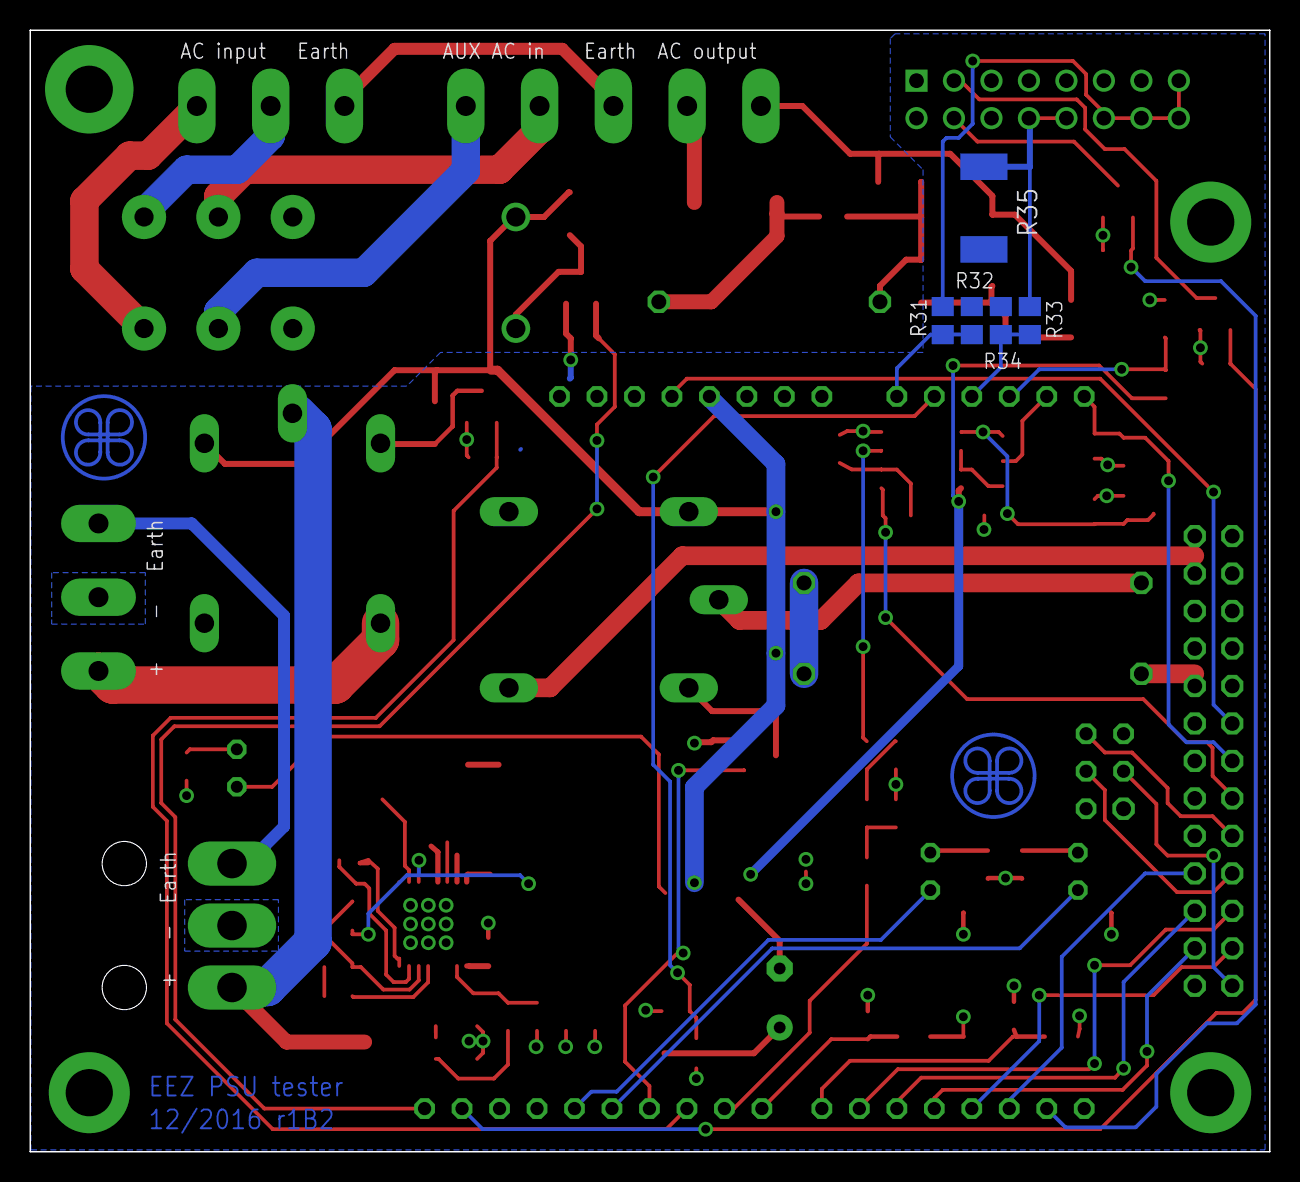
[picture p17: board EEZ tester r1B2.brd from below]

Board: 2 copper layers, 84.0 x 76.0 mm, 91 parts (5 on the bottom side), 76 nets.

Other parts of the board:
EEZ_SIGNATURE, EEZ_SIGNATURE2: SIGNATURESMALL; SIGNATURE_5MM

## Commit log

2016-12-27 inital push
    [EEZ tester (Power + AUX PS).GBL, EEZ tester (Power + AUX PS).GBO, EEZ tester (Power + AUX PS).GBS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]
2016-12-27 PCB layout pictures
2016-12-27 Eagle and license files
    [EEZ tester r1B2.brd, EEZ tester r1B2.sch]
2017-01-22 Arduino rotated ICSP fixed
    [EEZ tester (Power + AUX PS).GBL, EEZ tester (Power + AUX PS).GTO, EEZ tester r1B3.GBL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]
2017-01-22 parts value corrections
    [EEZ tester r1B3.GBL, EEZ tester r1B3.GBO, EEZ tester r1B3.GBS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]
2017-02-02 pinout redefinition
    [EEZ tester r1B3.GBL, EEZ tester r1B3.GBO, EEZ tester r1B3.GBS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]
2017-08-21 README.md pic fixed
    [EEZ tester r1B3.GBL, EEZ tester r1B3.GBO, EEZ tester r1B3.GBS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]
